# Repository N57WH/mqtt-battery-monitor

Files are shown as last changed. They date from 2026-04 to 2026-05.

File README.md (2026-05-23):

# 12V Battery Voltage Monitor v2.0

Monitors a 12V battery and reports voltage, SOC, and charge trending
to Home Assistant via MQTT. All calculations run on the ESP32 — no
Home Assistant configuration files needed. Sensors auto-discover
under one device via MQTT discovery.

Screenshot 2026-05-22 at 8 57 35 PM

## Repository layout

```
mqtt-battery-monitor/
├── src/        ← Arduino sketch + secrets.h template
├── docs/       ← Sensor reference and additional notes
├── assets/     ← Wiring diagram (SVG)
└── Hardware/   ← 3D printable case (STL) + render
```

## What it reports

| Sensor | Type | Description |
|---|---|---|
| Battery Voltage | sensor | Volts from INA260 (3 decimal places) |
| Battery SOC | sensor | State of charge (%) from voltage lookup |
| Voltage Trend | sensor | Rate of change (V/hr, 30-min rolling) |
| Battery Trend | sensor | Label: Charging / Stable / Discharging |
| Battery Low | binary_sensor | ON when SOC drops below 20% |
| Battery Chemistry | select | Flooded / AGM / LiFePO4 (changeable from HA) |

Chemistry selection persists across reboots (saved to NVS flash).

## Hardware

| Component | Purpose |
|---|---|
| [Seeed XIAO ESP32-C6](https://wiki.seeedstudio.com/xiao_esp32c6_getting_started/) | Microcontroller + WiFi |
| [Adafruit DC Power BFF](https://learn.adafruit.com/adafruit-dc-power-bff) | 12V → 5V buck converter, plugs under XIAO |
| [Adafruit INA260](https://learn.adafruit.com/adafruit-ina260-current-voltage-power-sensor-breakout) | I2C voltage sensor (0–36V) |
| 12V battery | Device under test |
| 2.1mm DC jack cable | Connects battery to BFF |

### Enclosure

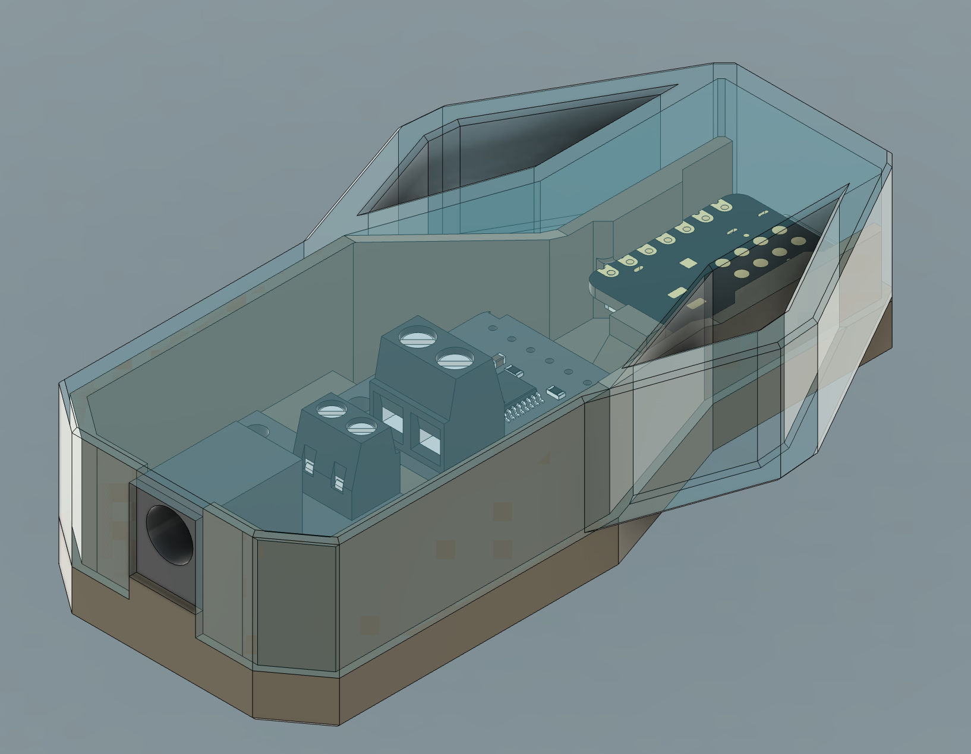
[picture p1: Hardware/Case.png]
Case render


STL files for the enclosure and cover are in [`Hardware/`](./Hardware):
[`Case.stl`](./Hardware/Case.stl) and [`Cover.stl`](./Hardware/Cover.stl).

## Wiring

### XIAO ESP32-C6 pin mapping

| Board silk | GPIO | Function |
|---|---|---|
| D0 | GPIO0 | — |
| D1 | GPIO1 | — |
| D2 | GPIO2 | — |
| D3 | GPIO21 | — |
| **D4** | **GPIO22** | **SDA (I2C data)** |
| **D5** | **GPIO23** | **SCL (I2C clock)** |
| D6 | GPIO16 | TX |
| D7 | GPIO17 | RX |
| D8 | GPIO19 | — |
| D9 | GPIO20 | — |
| D10 | GPIO18 | — |
| **3V3** | — | **3.3V output** |
| 5V | — | From BFF (internal) |
| GND | — | From BFF (internal) |
| LED | GPIO15 | On-board yellow LED |

**Note:** GPIO22/GPIO23 for I2C is specific to the XIAO ESP32-C6.
The older XIAO ESP32-C3 uses GPIO6/GPIO7. Do not mix them up.

### Connections (5 wires + jumper)

| From | To | Wire color |
|---|----|---|
| Battery 12V | BFF 2.1mm DC jack | DC jack cable |
| BFF terminal block (+) | INA260 screw terminal Vin+ | 12V sense |
| BFF terminal block (−) | INA260 header GND | Ground |
| XIAO 3V3 | INA260 header Vcc | 3.3V logic power |
| XIAO D4 (GPIO22) | INA260 header SDA | I2C data |
| XIAO D5 (GPIO23) | INA260 header SCL | I2C clock |
| INA260 Vin+ | INA260 Vin- | **Jumper wire** |

See [`assets/battery_wiring_diagram_v2.svg`](./assets/battery_wiring_diagram_v2.svg) for the full wiring diagram.

### Voltage-only jumper

The INA260 has a 2mΩ internal shunt between Vin+ and Vin-. For
voltage-only monitoring (no current measurement), place a short
jumper wire between the Vin+ and Vin- screw terminals on the
INA260 breakout. This gives the shunt inputs a defined DC path
while allowing the chip to read bus voltage normally via the
on-board VBus connection (tied to Vin+ by default through the
VB jumper on the breakout PCB).

### INA260 breakout header pins (left to right)

| Pin | Connected | Notes |
|-----|---|---|
| GND | Yes | Ground |
| Vcc | Yes | 3.3V from XIAO |
| SCL | Yes | I2C clock from D5 |
| SDA | Yes | I2C data from D4 |
| Alert | No | Not used |
| VBus | No | Tied to Vin+ on-board |
| Vin+ | No | Using screw terminal instead |
| Vin- | No | Using screw terminal instead |

### Power path

Battery 12V enters the BFF through the 2.1mm DC jack (on-board,
soldered to the BFF PCB). The BFF's MPM3610 buck converter steps
12V down to 5V and delivers it to the XIAO through the socket
headers. No external wiring between BFF and XIAO — the 5V and
GND connections are made through the socket pins. The BFF terminal
block provides a 12V pass-through to the INA260 for voltage sensing.

## Software setup

### Arduino IDE

1. **Add ESP32 board URL** in File → Preferences → Additional Board URLs:
   ```
   https://espressif.github.io/arduino-esp32/package_esp32_index.json
   ```

2. **Install board package**: Tools → Board Manager → search "XIAO esp32c6" → install

3. **Select board**: Tools → Board → esp32 → XIAO_ESP32C6

4. **Board settings**:
   - USB CDC On Boot: Enabled
   - CPU Frequency: 160MHz (WiFi)
   - Flash Size: 4MB
   - Partition Scheme: Default 4MB with spiffs (1.2MB APP/1.5MB SPIFFS)
   - Zigbee Mode: Disabled

5. **Install libraries** via Library Manager:
   - Adafruit INA260 Library (includes Adafruit BusIO)
   - PubSubClient by Nick O'Leary

6. **Edit `secrets.h`** with your WiFi SSID/password, MQTT broker IP,
   MQTT credentials, and OTA password

7. **Upload**: connect USB-C, select serial port, click Upload

### First boot

Open Serial Monitor at 115200 baud. You should see:

```
===================================
  Battery Voltage Monitor v2.0
  XIAO ESP32-C6 + INA260 + MQTT
  All sensors on-board
===================================
[NVS] Chemistry: Lead-Acid (Flooded)
[INA260] OK — 64x averaging, continuous
[INA260] I2C: SDA=GPIO22 (D4), SCL=GPIO23 (D5)
[WiFi] Connected — IP 192.168.x.x
[OTA] Ready on port 3232
[MQTT] connected
[MQTT] Discovery published (6 entities)
[READ] 12.847 V | SOC 95% | Trend 0.000 V/hr (Stable) | Lead-Acid (Flooded): OK
[MQTT] Publish → OK
```

### Home Assistant

No configuration needed. Once the ESP32 connects to your MQTT broker:

1. Go to Settings → Devices & Services → MQTT
2. A device called "Battery Monitor" appears with 6 entities
3. Add entities to any dashboard

To change battery chemistry, find the "Battery Chemistry" select
entity in HA and choose Flooded / AGM / LiFePO4. The ESP32 saves
the selection and recalculates SOC immediately.

## OTA updates

After the first USB flash, firmware updates go over WiFi.

### macOS firewall

OTA requires the ESP32 to connect *back* to your computer. If you
see "No response from device" after authentication succeeds:

- System Settings → Network → Firewall → allow python3
- Or temporarily disable the firewall during upload

### Serial Monitor

Serial Monitor only works over USB, not over the network port.
Once firmware is stable, debug output isn't needed — everything
is visible in Home Assistant via the MQTT entities.

## LED behavior

| LED state | Meaning |
|---|---|
| Solid on | WiFi + MQTT connected, sensor OK |
| Blinking | Connecting to WiFi |
| Off | INA260 not found (check wiring) |
| Flashing during upload | OTA in progress |

## Sensor Calculations  (See docs/SENSOR.MD)

SOC is estimated via voltage-based piecewise linear interpolation
using open-circuit voltage tables for three battery chemistries:

| Chemistry | Nominal | 100% OCV | 0% OCV |
|---|---|---|---|
| Lead-Acid (Flooded) | 12.6V | 12.73V | 11.31V |
| Lead-Acid (AGM) | 12.8V | 12.80V | 11.51V |
| LiFePO4 (4S) | 12.8V | 13.60V | 11.20V |

Accuracy is ±5–10% for lead-acid, ±10–15% for LiFePO4 (very
flat discharge curve). Most accurate when battery has been at
rest for 15–30 minutes.

## Voltage trending

The ESP32 maintains a 30-sample circular buffer (30 minutes at
60s intervals). Trend is calculated by comparing the average of
the oldest half against the newest half, converted to V/hr.

| Trend rate | Label |
|---|---|
| > +0.1 V/hr | Charging fast |
| > +0.02 V/hr | Charging |
| < −0.1 V/hr | Discharging fast |
| < −0.02 V/hr | Discharging |
| otherwise | Stable |

The trend buffer fills gradually after boot — the first 2 minutes
show 0.000 V/hr until enough samples accumulate.

## Files

```
battery_monitor_mqtt/
├── battery_monitor_mqtt.ino   ← main sketch (all sensors on-board)
├── secrets.h                  ← WiFi, MQTT, OTA credentials
└── README.md
```

## Troubleshooting

| Problem | Fix |
|---|-----|
| INA260 NOT FOUND | Check D4→SDA, D5→SCL, 3V3→Vcc, GND→GND. Verify address 0x40. |
| Wrong GPIO for I2C | XIAO ESP32-C6 uses GPIO22/23, NOT GPIO6/7 (that's the C3). |
| WiFi won't connect | 2.4 GHz only. Check SSID/password in secrets.h. |
| MQTT failed rc=-2 | Broker IP wrong or port 1883 blocked by firewall. |
| MQTT failed rc=5 | Wrong MQTT username or password. |
| OTA: No response | macOS firewall blocking return connection. Allow python3. |
| OTA: port error | Arduino IDE 2.x bug. Use espota.py command line instead. |
| Voltage reads 0 | Jumper Vin+ to Vin- on screw terminal. Check 12V at BFF terminal +. |
| SOC reads 0% | Select correct battery chemistry in HA. |
| Sensors not in HA | Check MQTT integration is active. Restart HA if needed. |

## Adding current monitoring later

To measure load current in the future:

1. Remove the jumper between Vin+ and Vin-
2. Wire Vin- to your load's positive terminal
3. Load current flows through the INA260's 2mΩ shunt
4. Add current and power MQTT discovery messages to the sketch
5. Current and power readings become non-zero

No hardware changes to the XIAO or BFF — only the INA260 wiring
and a firmware update.

## License

MIT

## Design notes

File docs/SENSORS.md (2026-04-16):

# Battery Monitor — Sensor Output Reference

Documentation for the six sensors published by the Battery Monitor
device in Home Assistant. All values are calculated on the ESP32
and published via MQTT every 60 seconds.

---

## Sensors at a glance

| Entity | Type | Unit | Example |
|---|---|---|---|
| Battery Voltage | sensor | V | 12.847 |
| Battery SOC | sensor | % | 75 |
| Voltage Trend | sensor | V/hr | -0.023 |
| Battery Trend | sensor | — | Stable |
| Battery Condition | binary_sensor | — | Normal |
| Battery Chemistry | select | — | Lead-Acid (Flooded) |

---

## Battery Voltage

The raw voltage reading from the INA260 sensor. The chip measures
bus voltage at the VBus pin (tied to Vin+ on the breakout) with
a 1.25 mV resolution and 16-bit ADC. The firmware applies 64-sample
hardware averaging with 1.1 ms conversion time for a clean, stable
reading.

The value is reported in volts to three decimal places (e.g. 12.847 V).

This is the open-circuit voltage (OCV) of the battery if no load is
connected, or the terminal voltage under load if a charger or load
is present. SOC accuracy is highest when the battery has been at
rest for 15–30 minutes — surface charge from recent charging or
voltage sag from a load will skew the reading.

---

## Battery SOC (State of Charge)

Estimated percentage of charge remaining in the battery, calculated
from voltage using piecewise linear interpolation against a lookup
table matched to the selected chemistry.

### How it works

The firmware stores a table of (voltage, SOC%) data points for each
chemistry. When a voltage reading comes in, the code finds which two
table entries the voltage falls between, calculates the fractional
position, and interpolates the SOC value.

Example: a Flooded battery reading 12.42 V falls between the 12.37 V
(70%) and 12.48 V (80%) entries.

```
fraction = (12.42 - 12.37) / (12.48 - 12.37) = 0.45
SOC = 70 + (0.45 × 10) = 75%
```

Voltages above the 100% entry return 100%. Voltages below the 0%
entry return 0%.

### Lookup tables

#### Lead-Acid (Flooded)

| Resting voltage | SOC |
|---|-----|
| 12.73 V | 100% |
| 12.58 V | 90% |
| 12.48 V | 80% |
| 12.37 V | 70% |
| 12.28 V | 60% |
| 12.17 V | 50% |
| 12.06 V | 40% |
| 11.96 V | 30% |
| 11.81 V | 20% |
| 11.66 V | 10% |
| 11.51 V | 5% |
| 11.31 V | 0% |

#### Lead-Acid (AGM)

| Resting voltage | SOC |
|---|-----|
| 12.80 V | 100% |
| 12.62 V | 90% |
| 12.50 V | 80% |
| 12.42 V | 70% |
| 12.32 V | 60% |
| 12.20 V | 50% |
| 12.11 V | 40% |
| 12.06 V | 30% |
| 11.96 V | 20% |
| 11.81 V | 10% |
| 11.66 V | 5% |
| 11.51 V | 0% |

#### LiFePO4 (4S, 12.8V nominal)

| Resting voltage | SOC |
|---|-----|
| 13.60 V | 100% |
| 13.40 V | 95% |
| 13.35 V | 90% |
| 13.30 V | 80% |
| 13.28 V | 70% |
| 13.20 V | 50% |
| 13.10 V | 30% |
| 13.00 V | 20% |
| 12.80 V | 10% |
| 12.00 V | 5% |
| 11.20 V | 0% |

### Accuracy

Voltage-based SOC estimation has inherent limitations:

- **Lead-acid**: ±5–10%. The voltage curve is reasonably spread
  across the SOC range, giving usable resolution at every level.

- **LiFePO4**: ±10–15%. The discharge curve is very flat between
  20–80% SOC (only ~0.3 V spans 60% of capacity), making it hard
  to distinguish mid-range states from voltage alone.

- **Under load**: voltage sag causes under-reading. A battery at
  80% SOC may show 70% under heavy draw.

- **After charging**: surface charge causes over-reading. A battery
  just taken off a charger may show 100% but settle to 90% after
  15–30 minutes of rest.

### Changing chemistry

The "Battery Chemistry" select entity in Home Assistant lets you
switch between the three lookup tables at any time. The selection
is saved to the ESP32's NVS flash and persists across reboots.
SOC recalculates immediately on the next 60-second cycle.

---

## Voltage Trend

The rate of voltage change in volts per hour (V/hr), calculated
from a rolling 30-minute buffer of readings.

### How it works

The ESP32 maintains a circular buffer of 30 voltage samples, one
per minute. Each cycle the buffer is split into two halves:

```
Oldest 15 samples → average A
Newest 15 samples → average B

delta = B - A
minutes between midpoints = 15 minutes
trend = delta × (60 / 15) = delta × 4 → V/hr
```

This approach smooths out noise while still detecting genuine
trends. A single noisy reading doesn't move the needle — it takes
a sustained change over multiple minutes to shift the trend value.

### Reading the value

| Value | Meaning |
|---|---|
| +0.150 V/hr | Voltage rising steadily — charger active |
| +0.030 V/hr | Slight rise — trickle charge or recovery |
| -0.001 V/hr | Essentially flat — resting battery |
| -0.050 V/hr | Gradual decline — light load |
| -0.300 V/hr | Rapid drop — heavy discharge or problem |

### Startup behavior

The buffer fills gradually after boot. During the first 2 minutes
the trend reads 0.000 V/hr because there aren't enough samples to
compare. After 30 minutes the buffer is full and the trend reflects
the complete half-hour window.

### Dashboard charting

Add a History Graph card in Home Assistant to visualize the voltage
trend over time:

```yaml
type: history-graph
title: Voltage trend (24h)
hours_to_show: 24
entities:
  - entity: sensor.battery_monitor_voltage_trend
```

Overlay it with the voltage graph to correlate:

```yaml
type: history-graph
title: Battery voltage and trend
hours_to_show: 24
entities:
  - entity: sensor.battery_monitor_battery_voltage
  - entity: sensor.battery_monitor_voltage_trend
```

Useful patterns to watch for in the charts:

- **Sawtooth voltage + positive trend**: charger cycling between
  bulk and float stages. Normal for lead-acid.

- **Flat voltage + zero trend**: battery at rest, no load, no
  charger. Ideal for accurate SOC readings.

- **Declining voltage + negative trend**: active discharge.
  Steeper slope = heavier load.

- **Voltage dropping then flattening**: load was removed, battery
  recovering toward open-circuit voltage.

- **Sudden voltage drop**: large load switched on, or a cell
  failing. Check if it recovers when load is removed.

---

## Battery Trend (label)

A plain-text label derived from the voltage trend value. Easier to
read at a glance than the raw V/hr number.

| Trend rate | Label |
|---|---|
| Above +0.10 V/hr | Charging fast |
| +0.02 to +0.10 V/hr | Charging |
| -0.02 to +0.02 V/hr | Stable |
| -0.10 to -0.02 V/hr | Discharging |
| Below -0.10 V/hr | Discharging fast |

The ±0.02 V/hr deadband around zero prevents the label from
flickering between "Charging" and "Discharging" due to noise
on a resting battery.

---

## Battery Condition

A binary sensor indicating whether the battery is low.

| SOC | State | HA display |
|-----|---|---|
| 20% or above | OFF | Normal |
| Below 20% | ON | Low |

This is a simple threshold check — `SOC < 20` → low. It does not
predict time remaining or account for discharge rate. Its primary
purpose is to trigger automations or dashboard warnings.

The 20% threshold was chosen because:

- **Lead-acid**: discharging below 20% SOC (~11.8 V) accelerates
  sulfation and shortens battery life significantly.

- **LiFePO4**: 20% SOC (~12.6 V) provides a safety margin above
  the BMS low-voltage cutoff, which is typically around 10–11 V.

---

## Dashboard examples

### Entities card

```yaml
type: entities
title: Battery monitor
entities:
  - entity: sensor.battery_monitor_battery_voltage
    name: Voltage
  - entity: sensor.battery_monitor_battery_soc
    name: SOC
  - entity: sensor.battery_monitor_battery_trend
    name: Trend
  - entity: sensor.battery_monitor_voltage_trend
    name: Trend rate
  - entity: binary_sensor.battery_monitor_battery_low
    name: Condition
  - entity: select.battery_monitor_battery_chemistry
    name: Chemistry
```

### SOC gauge

```yaml
type: gauge
entity: sensor.battery_monitor_battery_soc
name: State of charge
min: 0
max: 100
severity:
  green: 50
  yellow: 20
  red: 10
```

### Voltage history (24 hours)

```yaml
type: history-graph
title: Battery voltage
hours_to_show: 24
entities:
  - entity: sensor.battery_monitor_battery_voltage
```

### Voltage history (7 days)

```yaml
type: history-graph
title: Battery voltage (week)
hours_to_show: 168
entities:
  - entity: sensor.battery_monitor_battery_voltage
```

### SOC history

```yaml
type: history-graph
title: State of charge
hours_to_show: 24
entities:
  - entity: sensor.battery_monitor_battery_soc
```

---

## MQTT payload format

All sensors are published in a single JSON message every 60 seconds
to `homeassistant/sensor/battery_monitor/state`:

```json
{
  "voltage": 12.847,
  "soc": 75,
  "trend": -0.023,
  "trend_label": "Stable",
  "low": "OFF"
}
```

Chemistry state is published separately to
`homeassistant/select/battery_monitor_chemistry/state` and only
changes when the user selects a different chemistry in HA.

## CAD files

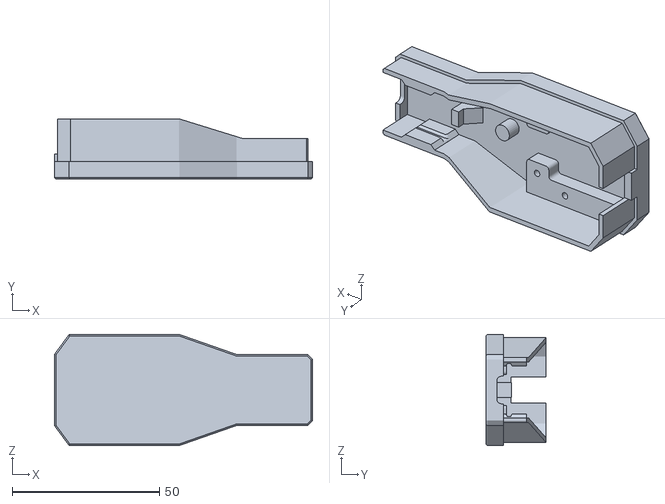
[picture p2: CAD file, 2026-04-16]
Hardware/Case.stl
87.5 x 20.5 x 37.7

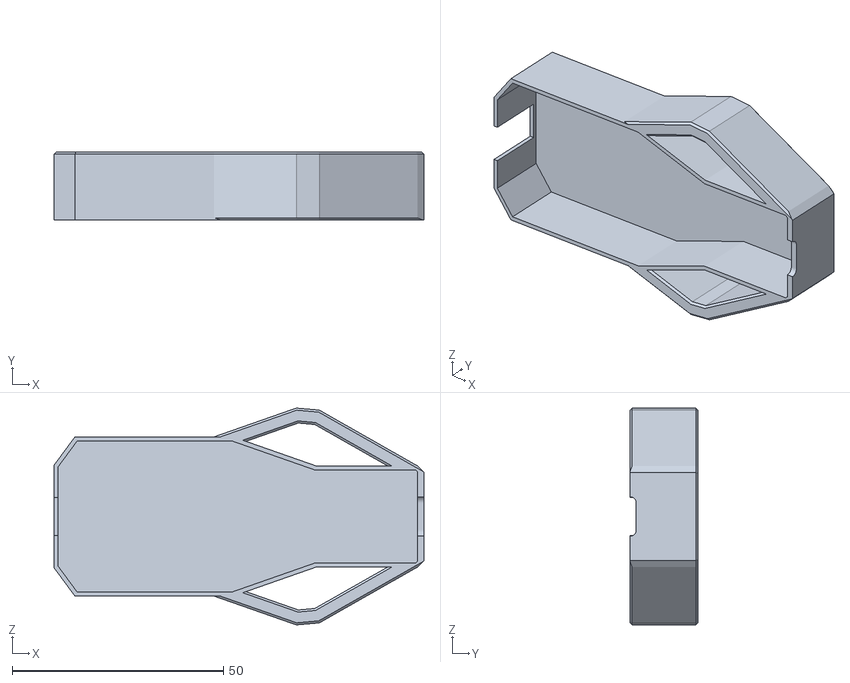
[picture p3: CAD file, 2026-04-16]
Hardware/Cover.stl
87.5 x 16.0 x 51.3

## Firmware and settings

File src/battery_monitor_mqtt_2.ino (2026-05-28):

// ============================================================
// Battery Voltage Monitor v2.0 — Device 2
// XIAO ESP32-C6 + INA260 + MQTT + OTA
// ============================================================
// Everything calculated on the ESP32:
//   - Voltage (from INA260)
//   - SOC (voltage lookup, 3 chemistries)
//   - Voltage trend (V/hr, rolling 30-min buffer)
//   - Trend label (Charging/Stable/Discharging)
//   - Battery low alert (SOC < 70%)
//   - Chemistry selector (MQTT Select, changeable from HA)
//
// Zero HA configuration needed — just MQTT integration.
// All sensors auto-discover under one device.
//
// Wiring:
//   XIAO D4 (GPIO22) → INA260 SDA
//   XIAO D5 (GPIO23) → INA260 SCL
//   XIAO 3V3         → INA260 Vcc
//   BFF terminal -   → INA260 GND
//   BFF terminal +   → INA260 Vin+ (jumpered to Vin-)
//   Battery 12V      → BFF DC jack
// ============================================================

#include <WiFi.h>
#include <PubSubClient.h>
#include <ArduinoOTA.h>
#include <Wire.h>
#include <Adafruit_INA260.h>
#include <Preferences.h>
#include "secrets.h"

// ---------- Hardware pins ----------
#define I2C_SDA    SDA          // GPIO22 (D4 on silk)
#define I2C_SCL    SCL          // GPIO23 (D5 on silk)
#define LED_PIN    LED_BUILTIN  // GPIO15

// ---------- INA260 ----------
#define INA260_ADDR  0x40

// ---------- Timing ----------
#define REPORT_INTERVAL_MS   60000   // publish every 60s
#define TREND_BUFFER_SIZE    30      // 30 samples = 30 minutes at 60s interval

// ---------- MQTT topics ----------
#define MQTT_PREFIX  "homeassistant"
#define DEVICE_ID    "battery_monitor_2"

// State topics
static const char* T_STATE      = MQTT_PREFIX "/sensor/" DEVICE_ID "/state";
static const char* T_AVAIL      = MQTT_PREFIX "/sensor/" DEVICE_ID "/availability";

// Discovery topics
static const char* T_DISC_VOLT  = MQTT_PREFIX "/sensor/" DEVICE_ID "_voltage/config";
static const char* T_DISC_SOC   = MQTT_PREFIX "/sensor/" DEVICE_ID "_soc/config";
static const char* T_DISC_TREND = MQTT_PREFIX "/sensor/" DEVICE_ID "_trend/config";
static const char* T_DISC_LABEL = MQTT_PREFIX "/sensor/" DEVICE_ID "_trend_label/config";
static const char* T_DISC_LOW   = MQTT_PREFIX "/binary_sensor/" DEVICE_ID "_low/config";
static const char* T_DISC_CHEM  = MQTT_PREFIX "/select/" DEVICE_ID "_chemistry/config";

// Select command/state topics
static const char* T_CHEM_CMD   = MQTT_PREFIX "/select/" DEVICE_ID "_chemistry/set";
static const char* T_CHEM_STATE = MQTT_PREFIX "/select/" DEVICE_ID "_chemistry/state";

// ---------- Chemistry types ----------
enum Chemistry { CHEM_FLOODED = 0, CHEM_AGM = 1, CHEM_LIFEPO4 = 2 };
static const char* CHEM_NAMES[] = { "Lead-Acid (Flooded)", "Lead-Acid (AGM)", "LiFePO4" };
static const int NUM_CHEMS = 3;

// ---------- SOC lookup tables [voltage_mV, soc_percent] ----------
// Lead-Acid Flooded (12V, 6-cell)
static const int16_t SOC_FLOODED[][2] = {
  {10500,  0}, {11310,  0}, {11510,  5}, {11660, 10},
  {11810, 20}, {11960, 30}, {12060, 40}, {12170, 50},
  {12280, 60}, {12370, 70}, {12480, 80}, {12580, 90},
  {12730,100}, {13200,100}
};
static const int SOC_FLOODED_LEN = sizeof(SOC_FLOODED) / sizeof(SOC_FLOODED[0]);

// Lead-Acid AGM
static const int16_t SOC_AGM[][2] = {
  {10500,  0}, {11510,  0}, {11660,  5}, {11810, 10},
  {11960, 20}, {12060, 30}, {12110, 40}, {12200, 50},
  {12320, 60}, {12420, 70}, {12500, 80}, {12620, 90},
  {12800,100}, {13200,100}
};
static const int SOC_AGM_LEN = sizeof(SOC_AGM) / sizeof(SOC_AGM[0]);

// LiFePO4 (4S, 12.8V nominal)
static const int16_t SOC_LFP[][2] = {
  {10000,  0}, {11200,  0}, {12000,  5}, {12800, 10},
  {13000, 20}, {13100, 30}, {13200, 50}, {13280, 70},
  {13300, 80}, {13350, 90}, {13400, 95}, {13600,100},
  {14600,100}
};
static const int SOC_LFP_LEN = sizeof(SOC_LFP) / sizeof(SOC_LFP[0]);

// ---------- Objects ----------
WiFiClient   wifiClient;
PubSubClient mqtt(wifiClient);
Adafruit_INA260 ina260;
Preferences  prefs;

// ---------- State ----------
bool          sensorOK     = false;
bool          discovSent   = false;
unsigned long lastReport   = 0;
Chemistry     chemistry    = CHEM_FLOODED;

// Trend buffer (circular, stores voltage in mV)
int32_t  trendBuf[TREND_BUFFER_SIZE];
int      trendHead  = 0;
int      trendCount = 0;

// Last published values (for change detection)
float    lastVoltage  = 0;
int      lastSOC      = -1;
float    lastTrend    = 0;
bool     lastLow      = false;
String   lastLabel    = "";

// ========================  LED  ========================

void ledOn()  { digitalWrite(LED_PIN, HIGH); }
void ledOff() { digitalWrite(LED_PIN, LOW);  }

// ========================  SOC lookup  ========================

int calcSOC(int32_t voltage_mV) {
  const int16_t (*table)[2];
  int len;

  switch (chemistry) {
    case CHEM_AGM:     table = SOC_AGM;     len = SOC_AGM_LEN;     break;
    case CHEM_LIFEPO4: table = SOC_LFP;     len = SOC_LFP_LEN;     break;
    default:           table = SOC_FLOODED;  len = SOC_FLOODED_LEN;  break;
  }

  if (voltage_mV <= table[0][0]) return table[0][1];
  if (voltage_mV >= table[len-1][0]) return table[len-1][1];

  for (int i = 0; i < len - 1; i++) {
    if (voltage_mV >= table[i][0] && voltage_mV < table[i+1][0]) {
      float frac = (float)(voltage_mV - table[i][0]) /
                   (float)(table[i+1][0] - table[i][0]);
      return (int)(table[i][1] + frac * (table[i+1][1] - table[i][1]) + 0.5f);
    }
  }
  return 0;
}

// ========================  Trend  ========================

void trendPush(int32_t voltage_mV) {
  trendBuf[trendHead] = voltage_mV;
  trendHead = (trendHead + 1) % TREND_BUFFER_SIZE;
  if (trendCount < TREND_BUFFER_SIZE) trendCount++;
}

// Returns trend in V/hr
float calcTrend() {
  if (trendCount < 2) return 0.0;

  // Average of oldest half vs newest half
  int half = trendCount / 2;
  float oldAvg = 0, newAvg = 0;

  for (int i = 0; i < half; i++) {
    int oldIdx = (trendHead - trendCount + i + TREND_BUFFER_SIZE) % TREND_BUFFER_SIZE;
    int newIdx = (trendHead - half + i + TREND_BUFFER_SIZE) % TREND_BUFFER_SIZE;
    oldAvg += trendBuf[oldIdx];
    newAvg += trendBuf[newIdx];
  }
  oldAvg /= half;
  newAvg /= half;

  // Time span: half * interval = minutes between the two halves
  float minutesBetween = half * (REPORT_INTERVAL_MS / 60000.0);
  if (minutesBetween < 0.1) return 0.0;

  float delta_mV = newAvg - oldAvg;
  float vPerHour = (delta_mV / minutesBetween) * 60.0 / 1000.0;  // mV/min → V/hr

  return vPerHour;
}

const char* trendLabel(float vPerHour) {
  if (vPerHour >  0.10) return "Charging fast";
  if (vPerHour >  0.02) return "Charging";
  if (vPerHour < -0.10) return "Discharging fast";
  if (vPerHour < -0.02) return "Discharging";
  return "Stable";
}

// ========================  WiFi  ========================

void connectWiFi() {
  if (WiFi.status() == WL_CONNECTED) return;

  Serial.printf("[WiFi] Connecting to %s ", WIFI_SSID);
  WiFi.mode(WIFI_STA);
  WiFi.setHostname("battery-monitor-2");
  WiFi.begin(WIFI_SSID, WIFI_PASS);

  int attempts = 0;
  while (WiFi.status() != WL_CONNECTED && attempts < 40) {
    delay(500);
    Serial.print(".");
    digitalWrite(LED_PIN, attempts % 2);
    attempts++;
  }

  if (WiFi.status() == WL_CONNECTED) {
    Serial.printf("\n[WiFi] Connected — IP %s\n", WiFi.localIP().toString().c_str());
    ledOn();
  } else {
    Serial.println("\n[WiFi] FAILED — will retry");
    ledOff();
  }
}

// ========================  MQTT  ========================

// Shared device JSON block for all discovery messages
String deviceBlock() {
  String d = "\"device\":{";
  d += "\"identifiers\":[\"" + String(DEVICE_ID) + "\"],";
  d += "\"name\":\"Battery Monitor 2\",";
  d += "\"model\":\"XIAO ESP32-C6 + INA260\",";
  d += "\"manufacturer\":\"DIY\",";
  d += "\"sw_version\":\"2.0\"";
  d += "}";
  return d;
}

void publishDiscovery() {
  String avail = "\"availability_topic\":\"" + String(T_AVAIL) + "\"";
  String state = "\"state_topic\":\"" + String(T_STATE) + "\"";
  String dev   = deviceBlock();

  // --- Voltage ---
  {
    String p = "{\"name\":\"Battery Voltage\",\"unique_id\":\"bat_mon_2_v\",";
    p += state + "," + avail + ",";
    p += "\"device_class\":\"voltage\",\"unit_of_measurement\":\"V\",";
    p += "\"value_template\":\"{{ value_json.voltage }}\",";
    p += "\"state_class\":\"measurement\",\"expire_after\":180,";
    p += "\"icon\":\"mdi:flash\"," + dev + "}";
    mqtt.publish(T_DISC_VOLT, p.c_str(), true);
  }

  // --- SOC ---
  {
    String p = "{\"name\":\"Battery SOC\",\"unique_id\":\"bat_mon_2_soc\",";
    p += state + "," + avail + ",";
    p += "\"device_class\":\"battery\",\"unit_of_measurement\":\"%\",";
    p += "\"value_template\":\"{{ value_json.soc }}\",";
    p += "\"state_class\":\"measurement\",\"expire_after\":180,";
    p += dev + "}";
    mqtt.publish(T_DISC_SOC, p.c_str(), true);
  }

  // --- Voltage Trend ---
  {
    String p = "{\"name\":\"Voltage Trend\",\"unique_id\":\"bat_mon_2_trend\",";
    p += state + "," + avail + ",";
    p += "\"unit_of_measurement\":\"V/hr\",";
    p += "\"value_template\":\"{{ value_json.trend }}\",";
    p += "\"state_class\":\"measurement\",\"expire_after\":180,";
    p += "\"icon\":\"mdi:chart-line\"," + dev + "}";
    mqtt.publish(T_DISC_TREND, p.c_str(), true);
  }

  // --- Trend Label ---
  {
    String p = "{\"name\":\"Battery Trend\",\"unique_id\":\"bat_mon_2_label\",";
    p += state + "," + avail + ",";
    p += "\"value_template\":\"{{ value_json.trend_label }}\",";
    p += "\"expire_after\":180,";
    p += "\"icon\":\"mdi:trending-neutral\"," + dev + "}";
    mqtt.publish(T_DISC_LABEL, p.c_str(), true);
  }

  // --- Battery Condition (binary sensor) ---
  {
    String p = "{\"name\":\"Battery Condition\",\"unique_id\":\"bat_mon_2_low\",";
    p += state + "," + avail + ",";
    p += "\"device_class\":\"battery\",";
    p += "\"value_template\":\"{{ value_json.low }}\",";
    p += "\"payload_on\":\"ON\",\"payload_off\":\"OFF\",";
    p += "\"expire_after\":180," + dev + "}";
    mqtt.publish(T_DISC_LOW, p.c_str(), true);
  }

  // --- Chemistry Select ---
  {
    String p = "{\"name\":\"Battery Chemistry\",\"unique_id\":\"bat_mon_2_chem\",";
    p += "\"command_topic\":\"" + String(T_CHEM_CMD) + "\",";
    p += "\"state_topic\":\"" + String(T_CHEM_STATE) + "\",";
    p += avail + ",";
    p += "\"options\":[\"Lead-Acid (Flooded)\",\"Lead-Acid (AGM)\",\"LiFePO4\"],";
    p += "\"icon\":\"mdi:battery-heart-variant\"," + dev + "}";
    mqtt.publish(T_DISC_CHEM, p.c_str(), true);
  }

  Serial.println("[MQTT] Discovery published (6 entities)");
  discovSent = true;
}

// Handle chemistry change from HA
void mqttCallback(char* topic, byte* payload, unsigned int length) {
  String msg;
  for (unsigned int i = 0; i < length; i++) msg += (char)payload[i];

  if (String(topic) == T_CHEM_CMD) {
    Serial.printf("[MQTT] Chemistry set to: %s\n", msg.c_str());

    Chemistry newChem = CHEM_FLOODED;
    if (msg == "Lead-Acid (AGM)")   newChem = CHEM_AGM;
    if (msg == "LiFePO4")           newChem = CHEM_LIFEPO4;

    if (newChem != chemistry) {
      chemistry = newChem;
      // Save to NVS so it persists across reboots
      prefs.begin("batmon", false);
      prefs.putInt("chem", (int)chemistry);
      prefs.end();
      Serial.printf("[NVS] Chemistry saved: %s\n", CHEM_NAMES[chemistry]);
    }

    // Publish back to confirm
    mqtt.publish(T_CHEM_STATE, CHEM_NAMES[chemistry], true);
  }
}

void connectMQTT() {
  if (mqtt.connected()) return;

  Serial.print("[MQTT] Connecting... ");
  mqtt.setServer(MQTT_SERVER, MQTT_PORT);
  mqtt.setBufferSize(600);
  mqtt.setCallback(mqttCallback);

  String clientId = "bat_mon_2_" + String((uint32_t)ESP.getEfuseMac(), HEX);

  bool ok;
  if (strlen(MQTT_USER) > 0) {
    ok = mqtt.connect(clientId.c_str(), MQTT_USER, MQTT_PASS,
                      T_AVAIL, 0, true, "offline");
  } else {
    ok = mqtt.connect(clientId.c_str(), NULL, NULL,
                      T_AVAIL, 0, true, "offline");
  }

  if (ok) {
    Serial.println("connected");
    mqtt.publish(T_AVAIL, "online", true);
    mqtt.subscribe(T_CHEM_CMD);

    if (!discovSent) publishDiscovery();

    // Publish current chemistry state
    mqtt.publish(T_CHEM_STATE, CHEM_NAMES[chemistry], true);
  } else {
    Serial.printf("failed (rc=%d)\n", mqtt.state());
  }
}

// ========================  INA260  ========================

bool initINA260() {
  Wire.begin(I2C_SDA, I2C_SCL);

  if (!ina260.begin(INA260_ADDR, &Wire)) {
    Serial.println("[INA260] NOT FOUND — check wiring:");
    Serial.println("         D4 (GPIO22) → SDA");
    Serial.println("         D5 (GPIO23) → SCL");
    Serial.println("         3V3 → Vcc, GND → GND");
    return false;
  }

  ina260.setAveragingCount(INA260_COUNT_64);
  ina260.setVoltageConversionTime(INA260_TIME_1_1_ms);
  ina260.setCurrentConversionTime(INA260_TIME_1_1_ms);
  ina260.setMode(INA260_MODE_CONTINUOUS);

  Serial.println("[INA260] OK — 64x averaging, continuous");
  Serial.printf("[INA260] I2C: SDA=GPIO%d (D4), SCL=GPIO%d (D5)\n", I2C_SDA, I2C_SCL);
  return true;
}

// ========================  OTA  ========================

void setupOTA() {
  ArduinoOTA.setHostname("battery-monitor-2");
  //ArduinoOTA.setPassword(OTA_PASSWORD);

  ArduinoOTA.onStart([]() {
    Serial.println("[OTA] Update starting...");
    mqtt.publish(T_AVAIL, "offline", true);
    mqtt.disconnect();
  });

  ArduinoOTA.onEnd([]() {
    Serial.println("\n[OTA] Complete, rebooting...");
  });

  ArduinoOTA.onProgress([](unsigned int progress, unsigned int total) {
    Serial.printf("[OTA] %u%%\r", progress / (total / 100));
    digitalWrite(LED_PIN, (progress / 5000) % 2);
  });

  ArduinoOTA.onError([](ota_error_t error) {
    Serial.printf("[OTA] Error %u\n", error);
  });

  ArduinoOTA.begin();
  Serial.println("[OTA] Ready on port 3232");
}

// ========================  Read & Publish  ========================

void readAndPublish() {
  if (!sensorOK) return;

  // Read voltage
  int32_t voltage_mV = (int32_t)(ina260.readBusVoltage());  // returns float mV
  float voltage_V = voltage_mV / 1000.0;

  // Push to trend buffer
  trendPush(voltage_mV);

  // Calculate SOC
  int soc = calcSOC(voltage_mV);

  // Calculate trend
  float trend = calcTrend();
  // Round to 3 decimal places
  trend = ((int)(trend * 1000 + (trend >= 0 ? 0.5 : -0.5))) / 1000.0;

  const char* label = trendLabel(trend);
  bool low = (soc < 70);

  // Log
  Serial.printf("[READ] %.3f V | SOC %d%% | Trend %.3f V/hr (%s) | %s: %s\n",
                voltage_V, soc, trend, label,
                CHEM_NAMES[chemistry], low ? "LOW" : "OK");

  // Build JSON state payload (all sensors in one message)
  char payload[200];
  snprintf(payload, sizeof(payload),
    "{\"voltage\":%.3f,\"soc\":%d,\"trend\":%.3f,\"trend_label\":\"%s\",\"low\":\"%s\"}",
    voltage_V, soc, trend, label, low ? "ON" : "OFF");

  if (mqtt.connected()) {
    bool ok = mqtt.publish(T_STATE, payload);
    Serial.printf("[MQTT] Publish → %s\n", ok ? "OK" : "FAIL");
  }
}

// ========================  setup  ========================

void setup() {
  Serial.begin(115200);
  delay(1000);

  pinMode(LED_PIN, OUTPUT);
  ledOff();

  Serial.println();
  Serial.println("===================================");
  Serial.println("  Battery Voltage Monitor 2 v2.0");
  Serial.println("  XIAO ESP32-C6 + INA260 + MQTT");
  Serial.println("  All sensors on-board");
  Serial.println("===================================");

  // Load saved chemistry from NVS
  prefs.begin("batmon", true);  // read-only
  chemistry = (Chemistry)prefs.getInt("chem", CHEM_FLOODED);
  prefs.end();
  Serial.printf("[NVS] Chemistry: %s\n", CHEM_NAMES[chemistry]);

  // INA260
  sensorOK = initINA260();
  if (!sensorOK) {
    Serial.println("[FATAL] INA260 not found — retrying every 30s");
  }

  // WiFi
  connectWiFi();

  // OTA
  setupOTA();

  // MQTT
  connectMQTT();

  // Trigger first reading immediately
  lastReport = millis() - REPORT_INTERVAL_MS;

  Serial.println("[READY] All sensors publishing every 60s");
  Serial.printf("[READY] OTA: battery-monitor-2 | IP: %s\n",
                WiFi.localIP().toString().c_str());
}

// ========================  loop  ========================

void loop() {
  ArduinoOTA.handle();

  // Maintain WiFi
  if (WiFi.status() != WL_CONNECTED) {
    ledOff();
    connectWiFi();
  }

  // Maintain MQTT
  if (!mqtt.connected()) {
    connectMQTT();
  }
  mqtt.loop();

  // Retry sensor if failed at boot
  if (!sensorOK) {
    static unsigned long lastRetry = 0;
    if (millis() - lastRetry > 30000) {
      lastRetry = millis();
      Serial.println("[INA260] Retrying...");
      sensorOK = initINA260();
      if (sensorOK) ledOn();
    }
    return;
  }

  // LED solid when connected
  if (WiFi.status() == WL_CONNECTED && mqtt.connected()) {
    ledOn();
  }

  // Periodic reading
  if (millis() - lastReport >= REPORT_INTERVAL_MS) {
    lastReport = millis();
    readAndPublish();
  }
}

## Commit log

2026-04-16 Add project files: README, sensor docs, wiring diagram SVG, secrets.h template
2026-04-16 Add main Arduino sketch (Battery_Monitor_MQTT.ino)
2026-04-16 README: embed Case render image inline under Hardware section
